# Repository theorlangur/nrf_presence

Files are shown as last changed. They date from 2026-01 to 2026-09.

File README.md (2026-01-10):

MCUBoot serial recovery:

speed issue:
changed ~/myapps/go/mynewt-mcumgr-cli/modified_mods/newtmgr@v0.0.0-20201028150837-60b2da78788c/nmxact/nmserial/serial_xport.go
specifically changed Sleep from 20ms to 1ms (there's one such sleep)
this upped transfer rate from ~ 830 bytes/s to ~ 4.5kb/s

speed issue update:
using mcumgr-client (rust-based tool), changed mtu to 4k and line input size to 8k
tweaked amount of retries + subsequent timeout duration (16 retries, 1000ms timeout)
and I'm getting an ok speed of ~ 6kb/s

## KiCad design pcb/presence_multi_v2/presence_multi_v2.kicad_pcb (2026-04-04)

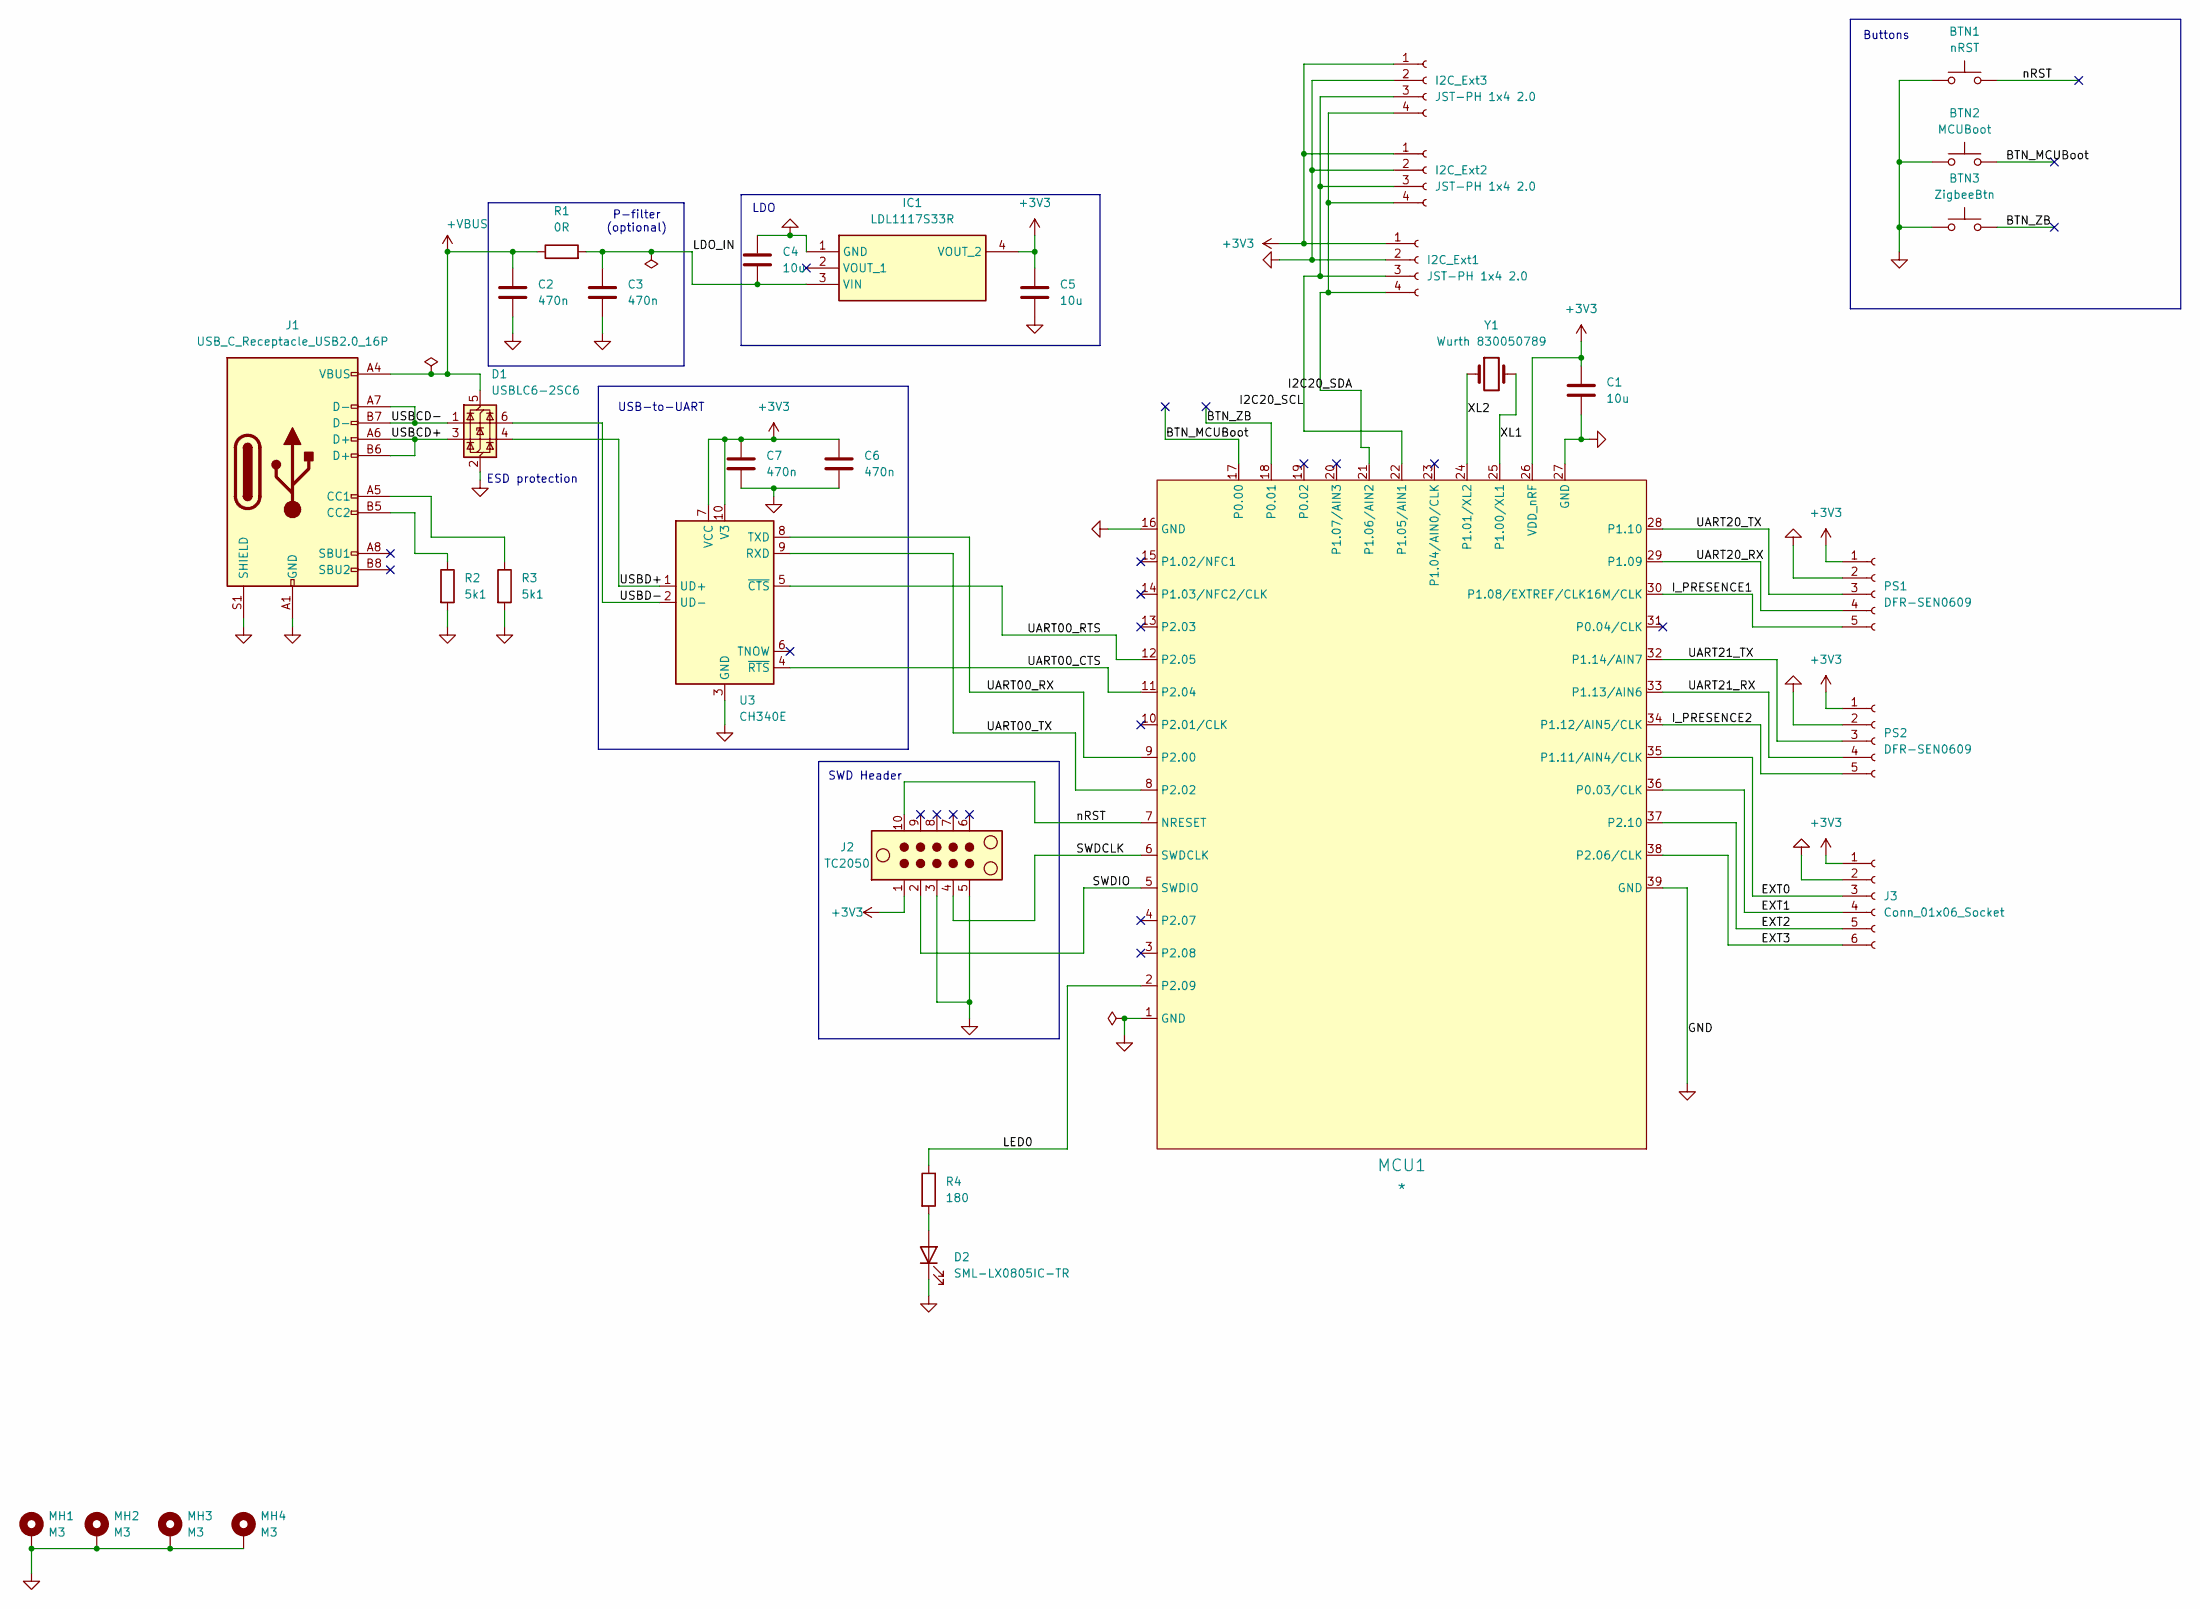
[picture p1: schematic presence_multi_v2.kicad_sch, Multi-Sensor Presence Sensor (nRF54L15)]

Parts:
BTN1: nRST; SW_SPST_TS-1088-xR020
BTN2: MCUBoot; SW_SPST_TS-1088-xR020
BTN3: ZigbeeBtn; SW_SPST_TS-1088-xR020
C1, C4, C5: 10u; C_0805_2012Metric
C2, C3, C6, C7: 470n; C_0805_2012Metric
D1: USBLC6-2SC6; SOT-23-6
D2: SML-LX0805IC-TR; LED_0805_2012Metric
I2C_Ext1, I2C_Ext2, I2C_Ext3: JST-PH 1x4 2.0; JST_PH_B4B-PH-K_1x04_P2.00mm_Vertical
IC1: LDL1117S33R; Mouser Part Number 511-LDL1117S33R
J1: USB_C_Receptacle_USB2.0_16P; USB_C_Receptacle_GCT_USB4105-xx-A_16P_TopMnt_Horizontal
J2: TC2050; Tag-Connect_TC2050-IDC-FP_2x05_P1.27mm_Vertical
J3: Conn_01x06_Socket; PinSocket_1x06_P2.54mm_Vertical
MCU1: *; Laird, BL54L15 Module, Platform Side
MH1, MH2, MH3, MH4: M3; MountingHole_3.5mm_Pad_Via
PS1, PS2: DFR-SEN0609; JST_PH_B5B-PH-K_1x05_P2.00mm_Vertical
R1: 0R; R_0805_2012Metric
R2, R3: 5k1; R_0805_2012Metric
R4: 180; R_0805_2012Metric
U3: CH340E; MSOP-10_3x3mm_P0.5mm
Y1: Wurth 830050789; Wurth-XTAL-830050789

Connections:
+3V3: C1.1, C5.1, C6.1, C7.1, I2C_Ext1.1, I2C_Ext2.1, I2C_Ext3.1, IC1.4 (VOUT_2), J2.1, J3.1, MCU1.26 (VDD_nRF), PS1.1, PS2.1, U3.7 (VCC), U3.10 (V3)
+VBUS: C2.1, D1.5 (VBUS), J1.A4 (VBUS), J1.A9 (VBUS), J1.B4 (VBUS), J1.B9 (VBUS), R1.1
/BTN_MCUBoot: BTN2.2, MCU1.17 (P0.00); also elsewhere on the board
/BTN_ZB: BTN3.2, MCU1.18 (P0.01); also elsewhere on the board
/EXT0: J3.3, MCU1.35 (P1.11/AIN4/CLK)
/EXT1: J3.4, MCU1.36 (P0.03/CLK)
/EXT2: J3.5, MCU1.37 (P2.10)
/EXT3: J3.6, MCU1.38 (P2.06/CLK)
/I2C20_SCL: I2C_Ext1.3, I2C_Ext2.3, I2C_Ext3.3, MCU1.22 (P1.05/AIN1)
/I2C20_SDA: I2C_Ext1.4, I2C_Ext2.4, I2C_Ext3.4, MCU1.21 (P1.06/AIN2)
/I_PRESENCE1: MCU1.30 (P1.08/EXTREF/CLK16M/CLK), PS1.5
/I_PRESENCE2: MCU1.34 (P1.12/AIN5/CLK), PS2.5
/LDO_IN: C3.1, C4.2, IC1.3 (VIN), R1.2
/LED0: MCU1.2 (P2.09), R4.1
/SWDCLK: J2.4, MCU1.6 (SWDCLK)
/SWDIO: J2.2, MCU1.5 (SWDIO)
/UART00_CTS: MCU1.11 (P2.04), U3.4 (~RTS)
/UART00_RTS: MCU1.12 (P2.05), U3.5 (~CTS)
/UART00_RX: MCU1.9 (P2.00), U3.8 (TXD)
/UART00_TX: MCU1.8 (P2.02), U3.9 (RXD)
/UART20_RX: MCU1.29 (P1.09), PS1.4
/UART20_TX: MCU1.28 (P1.10), PS1.3
/UART21_RX: MCU1.33 (P1.13/AIN6), PS2.4
/UART21_TX: MCU1.32 (P1.14/AIN7), PS2.3
/USBCD+: D1.3 (I/O2), J1.A6 (D+), J1.B6 (D+)
/USBCD-: D1.1 (I/O1), J1.A7 (D-), J1.B7 (D-)
/USBD+: D1.4 (I/O2), U3.1 (UD+)
/USBD-: D1.6 (I/O1), U3.2 (UD-)
/XL1: MCU1.25 (P1.00/XL1), Y1.2
/XL2: MCU1.24 (P1.01/XL2), Y1.1
/nRST: BTN1.2, J2.10, MCU1.7 (NRESET); also elsewhere on the board
GND: BTN1.1, BTN2.1, BTN3.1, C1.2, C2.2, C3.2, C4.1, C5.2, C6.2, C7.2, D1.2 (GND), D2.1 (K), I2C_Ext1.2, I2C_Ext2.2, I2C_Ext3.2, IC1.1 (GND), J1.A1 (GND), J1.A12 (GND), J1.B1 (GND), J1.B12 (GND), J1.S1 (SHIELD), J2.3, J2.5, J3.2, MCU1.1 (GND), MCU1.16 (GND), MCU1.27 (GND), MCU1.39 (GND), MH1.1, MH2.1, MH3.1, MH4.1, PS1.2, PS2.2, R2.2, R3.2, U3.3 (GND); also elsewhere on the board
unnamed: D2.2 (A), R4.2
unnamed: J1.A5 (CC1), R3.1
unnamed: J1.B5 (CC2), R2.1

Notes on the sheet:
SWD Header
ESD protection
P-filter (optional)
LDO
Buttons
USB-to-UART

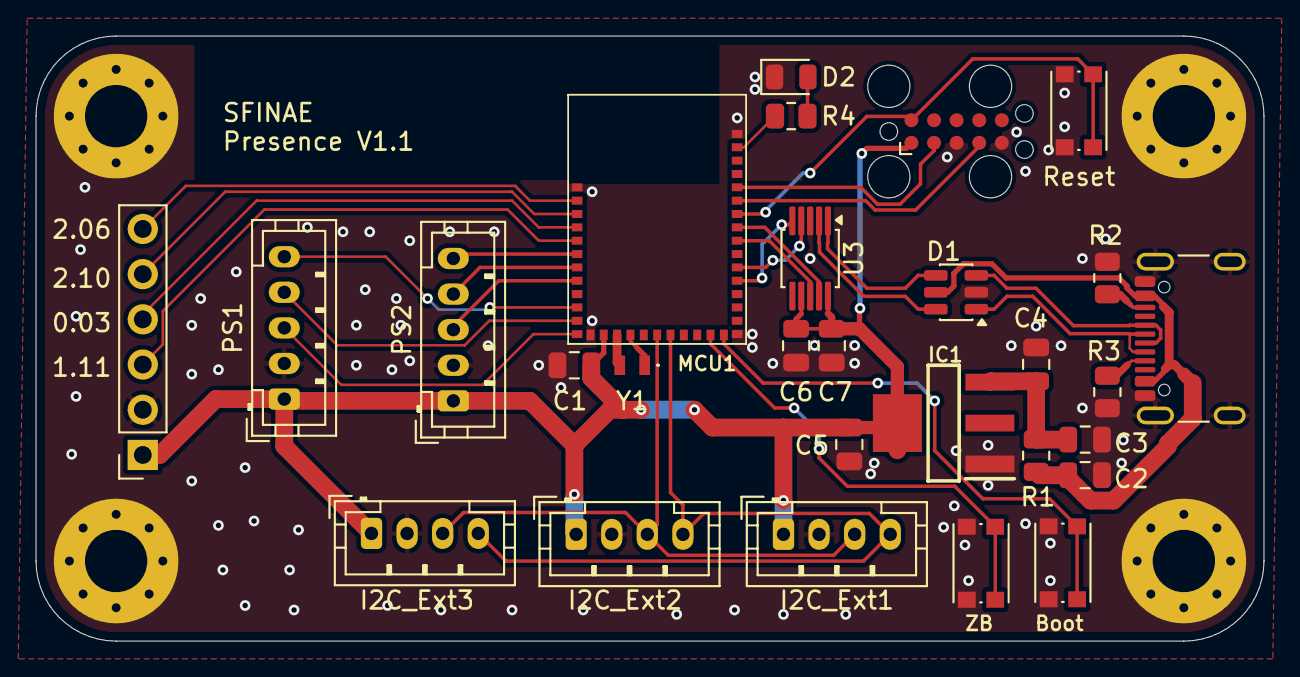
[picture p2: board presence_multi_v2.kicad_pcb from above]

Board: 2 copper layers, 69.0 x 34.0 mm, 32 parts (0 on the bottom side), 35 nets.

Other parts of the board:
Boot: MCUBoot; SW_Push_1P1T_NO_CK_KMR2
Reset: nRST; SW_Push_1P1T_NO_CK_KMR2
ZB: ZigbeeBtn; SW_Push_1P1T_NO_CK_KMR2

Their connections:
/BTN_MCUBoot: Boot.2; also elsewhere on the board
/BTN_ZB: ZB.2; also elsewhere on the board
/nRST: Reset.2; also elsewhere on the board
GND: Boot.1, Reset.1, ZB.1; also elsewhere on the board

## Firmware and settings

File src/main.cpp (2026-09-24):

/*
 * Copyright (c) 2023, Meta
 *
 * SPDX-License-Identifier: Apache-2.0
 */

#define FORCE_FMT
#define PRINTF_FUNC(...) printk(__VA_ARGS__)

#include <zephyr/kernel.h>
#include <zephyr/drivers/gpio.h>
#include <zephyr/settings/settings.h>
#include "ld2412_task.hpp"
#include <nrf_uart/periphery/lib_ld2412_formatters.hpp>
#include <dk_buttons_and_leds.h>
#include <nrf_general/led.h>

#include <zephyr/drivers/sensor.h>
#include <zephyr/drivers/sensor/ens160.h>

extern "C"{
#include <nrf_802154.h>
}

#include <zephyr/drivers/hwinfo.h>
#include <zephyr/drivers/watchdog.h>
#include <zephyr/storage/flash_map.h>
#include "threads_snapshot.hpp"
#include "partition_basic.hpp"
#include "activity_tracker.hpp"
/**********************************************************************/
/* Zigbee                                                             */
/**********************************************************************/
#include <nrfzbcpp/zb_main.hpp>
#include "zb/zb_mem_cfg.hpp"
#include <nrfzbcpp/zb_std_cluster_desc.hpp>
#include <nrfzbcpp/zb_status_cluster_desc.hpp>
#include <nrfzbcpp/zb_occupancy_sensing_cluster_desc.hpp>
#include <nrfzbcpp/zb_humid_cluster_desc.hpp>
#include <nrfzbcpp/zb_temp_cluster_desc.hpp>
#include <nrfzbcpp/zb_co2_cluster_desc.hpp>
#include <nrfzbcpp/zb_nstd_air_q_cluster_desc.hpp>
#include <nrfzbcpp/zb_tools.hpp>
#include "zb/zb_ld2412_cluster_desc.hpp"
#include "zb/zb_dev_ctrl_cluster_desc.hpp"

#include <atomic>

extern "C"{
#include <zephyr/debug/coredump.h>

void nrf_flash_skip_sync(bool skip);
}

constexpr bool kDebug = false;

#define BREADCRUMBS_PARTITION		breadcrumbs_partition
#define BREADCRUMBS_PARTITION_ID	FIXED_PARTITION_ID(BREADCRUMBS_PARTITION)

#if !FIXED_PARTITION_EXISTS(BREADCRUMBS_PARTITION)
#error "Need a fixed partition named 'breadcrumbs-partition'!"
#endif

/* Note that currently external memories are not supported */
#define FLASH_CONTROLLER	\
	DT_PARENT(DT_PARENT(DT_NODELABEL(BREADCRUMBS_PARTITION)))

#define FLASH_WRITE_SIZE	DT_PROP(FLASH_CONTROLLER, write_block_size)
#define FLASH_BUF_SIZE \
	MAX(FLASH_WRITE_SIZE, ROUND_UP(CONFIG_DEBUG_COREDUMP_FLASH_CHUNK_SIZE, FLASH_WRITE_SIZE))
#if DT_NODE_HAS_PROP(FLASH_CONTROLLER, erase_block_size)
#define DEVICE_ERASE_BLOCK_SIZE DT_PROP(FLASH_CONTROLLER, erase_block_size)
#else
/* Device has no erase block size */
#define DEVICE_ERASE_BLOCK_SIZE 1
#endif

#define MMWAVE_UART_NODE DT_ALIAS(mmwave_uart)
#define MMWAVE_UART_NODE2 DT_ALIAS(mmwave_uart2)
constinit const struct device *mmwave_uart1 = DEVICE_DT_GET(MMWAVE_UART_NODE);
constinit const struct device *mmwave_uart2 = DEVICE_DT_GET(MMWAVE_UART_NODE2);

/**********************************************************************/
/* LD2412 presence sensor configurations/data                         */
/**********************************************************************/
K_MSGQ_DEFINE_TYPED(ld2412::Queue, ld2412q_1);
K_MSGQ_DEFINE_TYPED(ld2412::Queue, ld2412q_2);

ld2412::Instance ld2412_1(ld2412q_1, mmwave_uart1, "ld2412_1");
ld2412::Instance ld2412_2(ld2412q_2, mmwave_uart2, "ld2412_2");

constinit static hlk::LD2412 *pLD2412_1 = nullptr;
constinit static hlk::LD2412 *pLD2412_2 = nullptr;

/**********************************************************************/
/* Zigbee Declarations and Definitions                                */
/**********************************************************************/
static bool g_ZigbeeReady = false;

/* Manufacturer name (32 bytes). */
#define INIT_BASIC_MANUF_NAME      "SFINAE"

/* Model number assigned by manufacturer (32-bytes long string). */
#define INIT_BASIC_MODEL_ID        "LD2412-NG"


/* Button used to enter the Bulb into the Identify mode. */
#define IDENTIFY_MODE_BUTTON            DK_BTN2_MSK

/* Button to start Factory Reset */
#define FACTORY_RESET_BUTTON IDENTIFY_MODE_BUTTON

/* Device endpoint, used to receive light controlling commands. */
constexpr int8_t kTX_POWER = 8;
constexpr uint8_t kMMW_EP = 1;
constexpr uint8_t kMMW_AUX_EP = 2;
constexpr uint16_t kDEV_ID = 0xBAAD;

constexpr uint16_t kInitialMinClearTimeout = 3;//seconds
constexpr uint32_t kZigbeeFloodProtectionTimeout = 1000;//ms
constexpr uint32_t kEnvSensorUpdateInterval = 15000;//ms
						    //
constexpr uint8_t kPersistentConfigVersion = 1;

struct device_ctx_t{
    zb::zb_zcl_basic_names_t basic_attr;
    zb::zb_zcl_status_t status_attr;
    zb::zb_zcl_status2_t status2_attr;
    zb::zb_zcl_dev_ctrl_t dev_attr;
    zb::zb_zcl_occupancy_pir_and_ultrasonic_t occupancy;
    zb::zb_zcl_on_off_attrs_client_t on_off_client;
    zb::zb_zcl_ld2412_t ld2412_main;
    zb::zb_zcl_ld2412_t ld2412_aux;
    zb::zb_zcl_rel_humid_basic_t humidity;
    zb::zb_zcl_temp_basic_t temperature;
    zb::zb_zcl_co2_basic_t co2;
    zb::zb_zcl_air_q_t airq;
};

//attribute shortcuts for template arguments

/**********************************************************************/
/* Status attribute shortcuts                                         */
/**********************************************************************/
constexpr auto kAttrStatus1 = &zb::zb_zcl_status_t::status1;
constexpr auto kAttrStatus2 = &zb::zb_zcl_status_t::status2;
constexpr auto kAttrStatus3 = &zb::zb_zcl_status_t::status3;

constexpr auto kA2Status1 = &zb::zb_zcl_status2_t::status1;
constexpr auto kA2Status2 = &zb::zb_zcl_status2_t::status2;
constexpr auto kA2Status3 = &zb::zb_zcl_status2_t::status3;
constexpr auto kA2Status4 = &zb::zb_zcl_status2_t::status4;

/**********************************************************************/
/* LD2412 attributes                                                  */
/**********************************************************************/
constexpr auto kAttrBaseCfg     = &zb::zb_zcl_ld2412_t::base_config;
constexpr auto kAttrStillThr    = &zb::zb_zcl_ld2412_t::still_energy_thresholds;
constexpr auto kAttrMoveThr     = &zb::zb_zcl_ld2412_t::move_energy_thresholds;
constexpr auto kAttrLightLevel  = &zb::zb_zcl_ld2412_t::light_level;
constexpr auto kAttrFlags       = &zb::zb_zcl_ld2412_t::flags;
constexpr auto kAttrBT          = &zb::zb_zcl_ld2412_t::bluetooth_state;
constexpr auto kAttrStatStill   = &zb::zb_zcl_ld2412_t::energy_stat_still;
constexpr auto kAttrStatMove    = &zb::zb_zcl_ld2412_t::energy_stat_move;
constexpr auto kAttrLightSense  = &zb::zb_zcl_ld2412_t::light_sense;
constexpr auto kAttrStatWinSize = &zb::zb_zcl_ld2412_t::statistics_sample_count_window;

/**********************************************************************/
/* Device control attributes                                          */
/**********************************************************************/
constexpr auto kAttrStillEnergyMain = &zb::zb_zcl_dev_ctrl_t::main_still_energy_analysis;
constexpr auto kAttrStillEnergyAux = &zb::zb_zcl_dev_ctrl_t::aux_still_energy_analysis;

/**********************************************************************/
/* Humidity                                                           */
/**********************************************************************/
constexpr auto kAttrHumid = &zb::zb_zcl_rel_humid_basic_t::measured_value;


/**********************************************************************/
/* Temperature                                                        */
/**********************************************************************/
constexpr auto kAttrTemp = &zb::zb_zcl_temp_basic_t::measured_value;

/**********************************************************************/
/* CO2                                                                */
/**********************************************************************/
constexpr auto kAttrCO2 = &zb::zb_zcl_co2_basic_t::measured_value;

/**********************************************************************/
/* Air quality                                                        */
/**********************************************************************/
constexpr auto kAttrTVOC = &zb::zb_zcl_air_q_t::tvoc;
constexpr auto kAttrAQI = &zb::zb_zcl_air_q_t::aqi;

/**********************************************************************/
/* Occupancy attribute shortcuts                                      */
/**********************************************************************/
constexpr auto kAttrOccupancy = &zb::zb_zcl_occupancy_ultrasonic_t::occupancy;
constexpr auto kAttrOccupancyToUnoccupancyDelay = &zb::zb_zcl_occupancy_ultrasonic_t::UltrasonicOccupiedToUnoccupiedDelay;

constexpr auto kCmdOn = &zb::zb_zcl_on_off_attrs_client_t::on;
constexpr auto kCmdOff = &zb::zb_zcl_on_off_attrs_client_t::off;

template<ld2412::Instance &i>
zb::cmd_handling_result_t on_cmd_restart();
template<ld2412::Instance &i>
zb::cmd_handling_result_t on_cmd_factory_reset();
template<ld2412::Instance &i>
zb::cmd_handling_result_t on_cmd_run_back_analysis();
template<ld2412::Instance &i>
zb::cmd_handling_result_t on_cmd_do_stat_snapshot();

zb::cmd_handling_result_t on_cmd_stop_wd_feeding();
zb::cmd_handling_result_t on_cmd_clear_coredump();

zb::cmd_handling_result_t on_cmd_start_analysis_for_presence();
zb::cmd_handling_result_t on_cmd_start_analysis_for_absence();
zb::cmd_handling_result_t on_cmd_stop_analysis();

/* Zigbee device application context storage. */
static constinit device_ctx_t dev_ctx{
    .basic_attr = {
	{
	    .zcl_version = ZB_ZCL_VERSION,
	    .power_source = zb::zb_zcl_basic_min_t::PowerSource::DC,
	},
	/*.manufacturer =*/ INIT_BASIC_MANUF_NAME,
	/*.model =*/ INIT_BASIC_MODEL_ID,
    },
    .status_attr{
	.cmd1 = {.cb = on_cmd_stop_wd_feeding}
	,.cmd2 = {.cb = on_cmd_clear_coredump}
    },
    .dev_attr{
	.cmd_start_analysis_for_presence = { .cb = on_cmd_start_analysis_for_presence }
	,.cmd_start_analysis_for_absense = { .cb = on_cmd_start_analysis_for_absence }
	,.cmd_stop_analysis              = { .cb = on_cmd_stop_analysis }
    },
    .ld2412_main{
	.still_energy_thresholds = zb::zb_zcl_ld2412_t::gate_array_t{100, 15, 15, 15, 15, 15, 15, 15, 15, 15, 15, 15, 15, 15}
	,.move_energy_thresholds = zb::zb_zcl_ld2412_t::gate_array_t{100, 15, 15, 15, 15, 15, 15, 15, 15, 15, 15, 15, 15, 15}
	,.cmd_restart = {.cb = on_cmd_restart<ld2412_1>}
	,.cmd_factory_reset = {.cb = on_cmd_factory_reset<ld2412_1>}
	,.cmd_run_background_analysis = {.cb = on_cmd_run_back_analysis<ld2412_1>}
	,.cmd_take_statistic_snapshot = {.cb = on_cmd_do_stat_snapshot<ld2412_1>}
    },
    .ld2412_aux{
	.still_energy_thresholds = zb::zb_zcl_ld2412_t::gate_array_t{100, 15, 15, 15, 15, 15, 15, 15, 15, 15, 15, 15, 15, 15}
	,.move_energy_thresholds = zb::zb_zcl_ld2412_t::gate_array_t{100, 15, 15, 15, 15, 15, 15, 15, 15, 15, 15, 15, 15, 15}
	,.cmd_restart = {.cb = on_cmd_restart<ld2412_2>}
	,.cmd_factory_reset = {.cb = on_cmd_factory_reset<ld2412_2>}
	,.cmd_run_background_analysis = {.cb = on_cmd_run_back_analysis<ld2412_2>}
	,.cmd_take_statistic_snapshot = {.cb = on_cmd_do_stat_snapshot<ld2412_2>}
    },
};

constinit static zb::device_full_t zb_ctx{
	zb::make_ep_args<{.ep=kMMW_EP, .dev_id=kDEV_ID, .dev_ver=1}>(
	    dev_ctx.basic_attr
	    , dev_ctx.status_attr
	    , dev_ctx.status2_attr
	    , dev_ctx.dev_attr
	    , dev_ctx.occupancy
	    , dev_ctx.ld2412_main
	    , dev_ctx.humidity
	    , dev_ctx.temperature
	    , dev_ctx.co2
	    , dev_ctx.airq
	    , dev_ctx.on_off_client
	),
	zb::make_ep_args<{.ep=kMMW_AUX_EP, .dev_id=kDEV_ID, .dev_ver=1}>(
	    dev_ctx.ld2412_aux
	)
};

/**********************************************************************/
/* Defining access to the global zigbee device context                */
/**********************************************************************/
//needed for proper command handling
struct zb::global_device
{
    static auto& get() { return zb_ctx; }
};

union status3_t
{
    uint16_t s;
    struct{
	uint16_t has_coredump: 1;
	uint16_t wdt_error: 1;
	uint16_t analysis_for_presence: 1;
	uint16_t analysis_for_absence: 1;
	uint16_t reset_reason_pin: 1;
	uint16_t reset_reason_wdt: 1;
	uint16_t reset_reason_sw: 1;
	uint16_t state_ld2412_back_main: 1;
	uint16_t state_ld2412_back_aux: 1;
	uint16_t state_ld2412_front_main: 1;
	uint16_t state_ld2412_front_aux: 1;
	uint16_t state_env: 1;
	uint16_t has_breadcrumbs: 1;
	uint16_t set_tx_error: 1;
	uint16_t incomplete_bread: 1;
	uint16_t osif_abort: 1;
    }bits;
};

//a shortcut for a convenient access
constinit static auto &zb_ep = zb_ctx.ep<kMMW_EP>();
constinit static auto &zb_ep_aux = zb_ctx.ep<kMMW_AUX_EP>();

template<ld2412::Instance &i>
auto& get_zb_ep_for_ld2412()
{
    if constexpr (&i == &ld2412_1)
	return zb_ep;
    else if constexpr (&i == &ld2412_2)
	return zb_ep_aux;
}

template<ld2412::Instance &i>
zb::zb_zcl_ld2412_t& get_data_for_ld2412()
{
    if constexpr (&i == &ld2412_1)
	return dev_ctx.ld2412_main;
    else if constexpr (&i == &ld2412_2)
	return dev_ctx.ld2412_aux;
}

template<ld2412::Instance &i>
const char* get_name_for_ld2412()
{
    if constexpr (&i == &ld2412_1)
	return "main";
    else if constexpr (&i == &ld2412_2)
	return "aux";
}

template<ld2412::Instance &i>
constexpr uint8_t get_ld2412_idx()
{
    if constexpr (&i == &ld2412_1)
	return 0;
    else if constexpr (&i == &ld2412_2)
	return 1;
}

/**********************************************************************/
/* Device defines                                                     */
/**********************************************************************/
/* The devicetree node identifier for the "led0" alias. */
#define LED0_NODE DT_ALIAS(userled0)

/*
 * A build error on this line means your board is unsupported.
 * See the sample documentation for information on how to fix this.
 */
static const struct gpio_dt_spec led0 = GPIO_DT_SPEC_GET(LED0_NODE, gpios);

///* Get the node from the alias */
#define SENSOR_NODE DT_ALIAS(presence)
#define SENSOR_NODE2 DT_ALIAS(presence2)
#define PIR_NODE2 DT_ALIAS(pir)

/* Get the GPIO spec directly from the node */
/* Note: We look for the property "gpios" inside the node */
static const struct gpio_dt_spec presence = GPIO_DT_SPEC_GET(SENSOR_NODE, gpios);
static const struct gpio_dt_spec presence2 = GPIO_DT_SPEC_GET(SENSOR_NODE2, gpios);
static const struct gpio_dt_spec pir = GPIO_DT_SPEC_GET(PIR_NODE2, gpios);

static const struct device *const eco2sensor = DEVICE_DT_GET(DT_NODELABEL(eco2sensor));
static const struct device *const rht2sensor = DEVICE_DT_GET(DT_NODELABEL(rht2sensor));

/**********************************************************************/
/* Template helper. TODO: move to some generic lib                    */
/**********************************************************************/
template<class T>
struct method_1st_arg_t;

template<class T, class Arg>
struct method_1st_arg_t<void(T::*)(Arg)>
{
    using type = Arg;
};

template<auto pM>
using arg1_type_t = method_1st_arg_t<decltype(pM)>::type;

template<auto &inst, auto M>
void method_fwd(arg1_type_t<M> a)
{
    (inst.*M)(a);
}

template<size_t N>
auto as_print_dest(zb::zigbee_str_t<N> &str)
{
    return tools::BufferFormatter(str.name + 1, str.capacity());
}

template<uint8_t kFlag>
using activity_t = zephyr::activity_t<kFlag>;
using zephyr::kLD2412_Front_Main;
using zephyr::kEnv;
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
int main(void)
{
    static_assert(atomic_state_t::is_always_lock_free);
    disable_hw_wdt();

    if (wdt_snapshot.is_valid())
    {
	//write into coredump section
	dump_wdt_snapshot_to_flash();
	wdt_snapshot.clear();
    }else if (wdt_snapshot.magic == zephyr::kSnapshotMagicNotReady)
    {
	printk("unfinished WDT snapshot detected\r\n");
	wdt_snapshot.clear();
    }

    int err = settings_subsys_init();
    hwinfo_get_reset_cause(&reset_reasons);
    hwinfo_clear_reset_cause();

    led::setup();
    led::start();

    zb::g_GlobalErrorHandler = ultimate_zb_fail;

    //configure button handler
    err = dk_buttons_init(button_changed);
    if (dk_get_buttons() & FACTORY_RESET_BUTTON)
    {
	//zigbee button is pressed
	zigbee_erase_persistent_storage(true);
	led::show_pattern(led::kPATTERN_4_BLIPS_NORMED, 500);
    }
    //assign a button for a factory reset procedure
    register_factory_reset_button(FACTORY_RESET_BUTTON);

    printk("main\r\n");

    pLD2412_1 = ld2412_1.setup(&on_ld2412_error<ld2412_1>, &on_ld2412_notify<ld2412_1>, 0, wdt_snapshot.flags);
    if(!pLD2412_1)
    {
	printk("LD2412 not found\r\n");
	int val = 1;
	while(true)
	{
	    gpio_pin_set_dt(&led0, val);
	    k_msleep(1000);
	    val ^= 1;
	    printk("LD2412 not found; led: %d\r\n", val);
	}
	return 0;
    }

    pLD2412_2 = ld2412_2.setup(&on_ld2412_error<ld2412_2>, &on_ld2412_notify<ld2412_2>, 1, wdt_snapshot.flags);
    if (!pLD2412_2)
    {
	printk("LD2412(aux) not found\r\n");
	int val = 1;
	while(true)
	{
	    gpio_pin_set_dt(&led0, val);
	    k_msleep(500);
	    val ^= 1;
	    printk("LD2412(aux) not found; led: %d\r\n", val);
	}
	return 0;
    }

    dev_ctx.occupancy.occupancy = false;

    /* Register callback for handling ZCL commands. */
    auto dev_cb = zb::tpl_device_cb<
	zb::dev_cb_handlers_desc_t{ .error_handler = on_dev_cb_error }
	//main instance
	, zb::handle_set_for<kAttrBaseCfg,               &on_set_base_config<ld2412_1>>(zb_ep)
	, zb::handle_set_for<kAttrLightSense,            &on_set_light_sense<ld2412_1>>(zb_ep)
	, zb::handle_set_for<kAttrStillThr,              method_fwd<ld2412_1, &ld2412::Instance::set_still_thresholds_raw>>(zb_ep)
	, zb::handle_set_for<kAttrMoveThr,               method_fwd<ld2412_1, &ld2412::Instance::set_move_thresholds_raw>>(zb_ep)
	, zb::handle_set_for<kAttrStatWinSize,           on_stat_win_size<ld2412_1>>(zb_ep)
	, zb::handle_set_for<kAttrOccupancyToUnoccupancyDelay, &on_change_occ_to_unocc>(zb_ep)
	, zb::handle_set_for<kAttrBT,                    method_fwd<ld2412_1, &ld2412::Instance::switch_bluetooth>>(zb_ep)
	//aux instance
	, zb::handle_set_for<kAttrBaseCfg,               &on_set_base_config<ld2412_2>>(zb_ep_aux)
	, zb::handle_set_for<kAttrLightSense,            &on_set_light_sense<ld2412_2>>(zb_ep_aux)
	, zb::handle_set_for<kAttrStillThr,              method_fwd<ld2412_2, &ld2412::Instance::set_still_thresholds_raw>>(zb_ep_aux)
	, zb::handle_set_for<kAttrMoveThr,               method_fwd<ld2412_2, &ld2412::Instance::set_move_thresholds_raw>>(zb_ep_aux)
	, zb::handle_set_for<kAttrStatWinSize,           on_stat_win_size<ld2412_2>>(zb_ep_aux)
	, zb::handle_set_for<kAttrBT,                    method_fwd<ld2412_2, &ld2412::Instance::switch_bluetooth>>(zb_ep_aux)
    >;

    ZB_ZCL_REGISTER_DEVICE_CB(dev_cb);

    /* Register device context (endpoints). */
    ZB_AF_REGISTER_DEVICE_CTX(zb_ctx);

    err = settings_load();

    //real config from the device takes precedense
    update_dev_ctx_from_ld2412<ld2412_1>();
    update_dev_ctx_from_ld2412<ld2412_2>();

    app_cfg_nvram_register();

    if (int err = configure_presence_pins(); err != 0)
    {
	printk("Failed to configure c4001 out pin\r\n");
    }
    {
	int p1 = gpio_pin_get_dt(&presence);
	int p2 = gpio_pin_get_dt(&presence2);
	int pirVal = gpio_pin_get_dt(&pir);
	g_presence_state = p1 | p2 | pirVal;
	printk("Presence pin state: %d\r\n", g_presence_state);
	dev_ctx.occupancy.occupancy = g_presence_state;
    }
    zigbee_enable();
    g_zboss_thread_id = zigbee_thread_id();

    printk("Main: sleep forever\r\n");
    FMT_PRINTLN("-----LD2412 main-----");
    print_ld2412_config(*pLD2412_1);
    FMT_PRINTLN("-----LD2412 aux-----");
    print_ld2412_config(*pLD2412_2);

    k_thread_start(env_sense_thread);
    while (1) {
	k_sleep(K_FOREVER);
    }

    return 0;
}

int configure_presence_pins()
{
    PresenceChange state;
    gpio_pin_configure_dt(&led0, GPIO_OUTPUT_ACTIVE);
    int err = gpio_pin_configure_dt(&presence, GPIO_INPUT);
    if (err != 0)
    {
	printk("(main)gpio_pin_configure_dt: %d\r\n", err);
	return err;
    }
    gpio_pin_set_dt(&led0, 0);

    err = gpio_pin_interrupt_configure_dt(&presence, GPIO_INT_EDGE_BOTH);
    if (err != 0)
    {
	printk("(main)gpio_pin_interrupt_configure_dt: %d\r\n", err);
	return err;
    }
    g_ld2412_main_presence_out = gpio_pin_get_dt(&presence);
    state.bits.main = g_ld2412_main_presence_out;
    printk("(main)initial: %d\r\n", g_ld2412_main_presence_out);

    err = gpio_pin_interrupt_configure_dt(&presence2, GPIO_INT_EDGE_BOTH);
    if (err != 0)
    {
	printk("(aux)gpio_pin_interrupt_configure_dt: %d\r\n", err);
	return err;
    }
    g_ld2412_aux_presence_out = gpio_pin_get_dt(&presence2);
    state.bits.aux = g_ld2412_aux_presence_out;
    printk("(aux)initial: %d\r\n", g_ld2412_aux_presence_out);

    err = gpio_pin_configure_dt(&pir, GPIO_INPUT);
    if (err != 0)
    {
	printk("(pir)gpio_pin_configure_dt: %d\r\n", err);
	return err;
    }
    err = gpio_pin_interrupt_configure_dt(&pir, GPIO_INT_EDGE_BOTH);
    if (err != 0)
    {
	printk("(pir)gpio_pin_interrupt_configure_dt: %d\r\n", err);
	return err;
    }
    g_pir_presence = gpio_pin_get_dt(&pir);
    state.bits.pir = g_pir_presence;

    dev_ctx.occupancy.occupancy = g_pir_presence;//initially only conservatively by PIR
    dev_ctx.status_attr.status2 = get_presence_as_status(state.val);

    g_ld2412_main_presence_out = gpio_pin_get_dt(&presence);
    g_ld2412_aux_presence_out = gpio_pin_get_dt(&presence2);

    gpio_init_callback(&g_on_ld2412_triggered_main, presence_triggered, BIT(presence.pin));
    err = gpio_add_callback_dt(&presence, &g_on_ld2412_triggered_main);
    if (!err)
    {
	gpio_init_callback(&g_on_ld2412_triggered_aux, presence_triggered, BIT(presence2.pin));
	err = gpio_add_callback_dt(&presence2, &g_on_ld2412_triggered_aux);
	if (!err)
	{
	    gpio_init_callback(&g_on_pir_triggered, presence_triggered, BIT(pir.pin));
	    err = gpio_add_callback_dt(&pir, &g_on_pir_triggered);
	    if (err != 0)
		printk("(pir)gpio_add_callback_dt: %d\r\n", err);
	}else
	    printk("(aux)gpio_add_callback_dt: %d\r\n", err);
    }else
	printk("(main)gpio_add_callback_dt: %d\r\n", err);
    return err;
}

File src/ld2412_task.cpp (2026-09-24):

#include "ld2412_task.hpp"
#include "activity_tracker.hpp"
#include <lib_misc_helpers.hpp>
#include <nrf_uart/periphery/lib_ld2412_formatters.hpp>

namespace ld2412
{
    Instance::Instance(Queue &q, const struct device *uart, const char* thread_name):
	m_ThreadName(thread_name)
	, m_Q(q)
	, m_pUART(uart)
	, m_Sensor(uart)
    {
    }

    hlk::LD2412* Instance::setup(err_callback_t err, notify_callback_t notification, uint8_t idx, volatile uint8_t &flags)
    {
	m_Idx = idx;
	m_pFlags = &flags;
	m_ThreadID = {};
	if (!device_is_ready(m_pUART))
	{
	    printk("uart for ld2412 is not ready\r\n");
	    return {};
	}

	zephyr::activity_rt_t track(*m_pFlags, zephyr::kLD2412_Back_Main << m_Idx);
	auto r = m_Sensor.Init();
	if (!r)
	    return {};

	r = m_Sensor.ChangeConfiguration()
	    .SetSystemMode(hlk::LD2412::SystemMode::Energy)
	.EndChange();
	if (!r)
	    return {};

	m_ErrCB = err;
	m_NotifyCB = notification;

	m_ThreadID = k_thread_create(&m_Thread 
	    ,m_ThreadStack
	    ,sizeof(m_ThreadStack)
	    ,thread_func
	    ,this, nullptr, nullptr
	    ,THREAD_PRIORITY
	    , 0
	    , {0});
	if (!m_ThreadID)
	    return {};
	k_thread_name_set(m_ThreadID, m_ThreadName);
	return &m_Sensor;
    }

    hlk::LD2412* Instance::sensor()
    {
	if (m_ThreadID)
	    return &m_Sensor;
	else
	    return {};
    }

    void Instance::restart()
    {
	m_Q << restart_cfg_t{};
    }
    void Instance::reload_config()
    {
	m_Q << reload_cfg_t{};
    }
    void Instance::factory_reset()
    {
	m_Q << factory_reset_cfg_t{};
    }
    void Instance::switch_bluetooth(bool on)
    {
	m_Q << bt_cfg_t{.on = on};
    }
    void Instance::set_basic_config(basic_cfg_t const& cfg)
    {
	m_Q << cfg;
    }
    void Instance::set_light_sense(light_sense_cfg_t const& cfg)
    {
	m_Q << cfg;
    }
    void Instance::set_still_thresholds(still_thresholds_cfg_t const& cfg)
    {
	FMT_PRINTLN("{} still thresholds: {}", m_ThreadName, cfg.still_thresholds);
	m_Q << cfg;
    }
    void Instance::set_move_thresholds(move_thresholds_cfg_t const& cfg)
    {
	FMT_PRINTLN("{} move thresholds: {}", m_ThreadName, cfg.move_thresholds);
	m_Q << cfg;
    }
    void Instance::run_back_analysis(run_background_analysis_t const& cfg)
    {
	m_Q << cfg;
    }
    void Instance::collect_statistics(uint8_t win_size)
    {
	m_Q << collect_statistics_cfg_t{win_size};
    }
    void Instance::take_statistic_snapshot(snapshot_statistics_cfg_t const& cfg)
    {
	m_Q << cfg;
    }

    void Instance::start_analysis_for_presence(start_analysis_for_presence_t const& cfg)
    {
	m_Q << cfg;
    }

    void Instance::start_analysis_for_absence(start_analysis_for_absence_t const& cfg)
    {
	m_Q << cfg;
    }

    void Instance::stop_analysis(stop_analysis_t const& cfg)
    {
	m_Q << cfg;
    }

    void Instance::get_analysis_results(hlk::LD2412::gate_array_t &results)
    {
	results = m_AnalysisStillEnergies;
    }

    void Instance::thread_func(void *_pThis, void *, void *)
    {
	Instance *pThis = (Instance*)(_pThis);
	return pThis->mainloop();
    }

    void Instance::collect_sample()
    {
	if (m_StatSampleCount)//we're collecting statistics
	{
	    auto &sample = m_StatSampleBuffer[m_StatSampleIndex];
	    sample.still_energies = m_Sensor.GetAllMeasuredStillEnergies();
	    sample.move_energies = m_Sensor.GetAllMeasuredMoveEnergies();
	    m_StatSampleIndex = (m_StatSampleIndex + 1) % m_StatSampleCount;
	    ++m_TotalSamplesWritten;
	}

	if (m_Analysis != AnalysisState::Stopped)
	{
	    auto const &measured = m_Sensor.GetAllMeasuredStillEnergies();
	    for(size_t i = 0; i < measured.size(); ++i)
	    {
		if (m_Analysis == AnalysisState::RunningForPresence)
		{
		    if (m_AnalysisStillEnergies[i] > measured[i])
			m_AnalysisStillEnergies[i] = measured[i];
		}
		if (m_Analysis == AnalysisState::RunningForAbsence)
		{
		    if (m_AnalysisStillEnergies[i] < measured[i])
			m_AnalysisStillEnergies[i] = measured[i];
		}
	    }
	}
    }

    void Instance::check_back_analysis()
    {
	if (m_BackgroundAnalysisDoneCB)
	{
	    run_background_analysis_t::Result r;
	    switch(m_Sensor.GetPresence().m_State)
	    {
		case hlk::LD2412::TargetState::BackgroundAnalysisOk:
		    r = run_background_analysis_t::Result::Ok;
		    break;
		case hlk::LD2412::TargetState::BackgroundAnalysisFailed:
		    r = run_background_analysis_t::Result::Failed;
		    break;
		case hlk::LD2412::TargetState::BackgroundAnalysisRunning:
		    return;
		default:
		    if (m_Sensor.IsDynamicBackgroundAnalysisRunning())
			return;
		    //assuming done
		    r = run_background_analysis_t::Result::Ok;
		    break;
	    }

	    m_BackgroundAnalysisDoneCB(r);
	    m_BackgroundAnalysisDoneCB = nullptr;

	    auto res = m_Sensor.ChangeConfiguration()
		.SetSystemMode(hlk::LD2412::SystemMode::Energy)
	    .EndChange();
	    if (!res)
	    {
		FMT_PRINTLN("{} Switching to Energy mode failed with: {}", m_ThreadName, res.error());
		if (m_ErrCB)
		    m_ErrCB(err_t::EnergyModeAfterBackAnalysis);
	    }
	}
    }

    void Instance::mainloop()
    {
	QueueItem q;
	bool processMessage = true;
	bool readFrameNow = false;

	auto last_frame_time = k_uptime_get();

	while(1)
	{
	    if (m_StatSampleCount || m_BackgroundAnalysisDoneCB || m_Analysis != AnalysisState::Stopped)
		readFrameNow = true;
	    else
	    {
		auto interval = m_LightSensorUpdateInterval;
		readFrameNow = (k_uptime_get() - last_frame_time) >= interval;
	    }

	    if (readFrameNow)
	    {
		zephyr::activity_rt_t track(*m_pFlags, zephyr::kLD2412_Back_Main << m_Idx);
		auto r = m_Sensor.TryReadSingleFrame(3, hlk::LD2412::Drain::Try);
		if (r)
		{
		    last_frame_time = k_uptime_get();
		    collect_sample();
		    check_back_analysis();
		}else
		    ++m_FrameReadErrorCount;
		processMessage = m_Q.Recv(q, K_NO_WAIT) == 0;
	    }
	    else
	    {
		m_Q >> q;
		processMessage = true;
	    }
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

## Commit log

2025-12-13 added kicad folder with schematics and other stuff
    [presence_multi_v2.kicad_pcb, presence_multi_v2.kicad_sch]
2025-12-13 started actual PCB design
    [presence_multi_v2.kicad_pcb, presence_multi_v2.kicad_sch]
2025-12-14 replaced ASM1117 with LDL1117, removed 8 pin socket, added 3 4-pin JST-PH connectors
    [presence_multi_v2.kicad_pcb, presence_multi_v2.kicad_sch]
2025-12-15 added buttons, configured PCB settings
    removed layers
    configured pre-defined ruls (constraints)
    added default sizes
    [presence_multi_v2.kicad_pcb, presence_multi_v2.kicad_sch]
2025-12-15 added GND net with color, updated PCB
    imported GND net, imported MCUBoot color
    [presence_multi_v2.kicad_sch]
2025-12-15 added a dedicated button for zigbee
    [presence_multi_v2.kicad_pcb, presence_multi_v2.kicad_sch]
2025-12-15 routing PCB
    [presence_multi_v2.kicad_pcb]
2025-12-16 ready version
    [presence_multi_v2.kicad_pcb, presence_multi_v2.kicad_sch]
2025-12-16 adjusted edge cuts (same radius used); adjusted some labels
    [presence_multi_v2.kicad_pcb]
2025-12-16 added info on components to a silkscreen
    [presence_multi_v2.kicad_pcb]
2026-01-09 refactored usb-to-uart into own dtsi
2026-01-09 added led blinking when dev not found
2026-01-09 MCUBoot: configured UART00 and using HW flow control
    important quirk: speed needs to be configured to 115200 so that the real
    speed 921600 can be used
2026-01-09 working version with MCUBoot
    had to adjust partition sizes
    MCUBoot partition is auto-calculated and the app offset is placed at a
    weird location
    adjusted atm the whole thing so that the slot0 is at 0xf800
    it works
    but 'list' command doesn't show any valid images
    [main.cpp]
2026-01-09 ok, the reason or baudrate mismatch is 128MHz clock frequence for uart00 instead of 16MHz
    so the requested 115200 are basically scaled up 8x to 921600
2026-01-09 added script to get uart output from usb-to-uart on board
2026-01-11 for whatever reason uart20 doesn't work well with pins 1.09 and 1.10 for rx/tx
    uart22 does
2026-01-11 circled back to uart20
    the reason was pinctrl misconfiguration
    original board pinctrl config provided pinconfig for uart20 in 2 groups
    with CTS pin and a different RX pin
    harmonized
2026-01-11 added 1 check for validity of uart
2026-01-12 added save/reset config to c4001 cluster description
    [main.cpp]
2026-01-12 added logic to reset zigbee when zigbee button is hold when reset
    [main.cpp]
2026-01-13 added configuration for i2c, added environment fetching
    using i2c21 instance since uart20 is already in use
    added clusters for temp/humidity/co2/tvoc/aqi
2026-01-13 forgot to start led thread
    also giving time for led to blink
2026-01-13 increased timeout, using udev rule to reference usb-to-uart ch340
2026-01-14 added 'Cortex-Debug' extension and enabled thread info
    finally I can see stack traces of all threads...
2026-01-18 enabled 2nd EP and added support for 2nd C4001 presence sensor
2026-01-18 2 c4001 sensors compile and run, as also 2 endpoints
2026-01-18 using dedicated symlink for running minicom for uart
2026-01-31 PCB: adjsuted DRU (were too strict)
2026-01-31 PCB: re-arranged the whole board
    made it significantly smaller
    used a slightly different footprint for buttons
    USB-C should be placed symmetrically now
    [presence_multi_v2.kicad_pcb]
2026-02-02 fixed bug with a presence logic
    pin 2 was ignored basically
    [main.cpp]
2026-02-02 added TX power support
2026-02-04 left one slot partition, increased the size of it
    was needed for dbg zigbee
2026-02-04 attempt to reboot like that causes a crash
    not rebooting...
    [main.cpp]
2026-02-04 increased resources for zigbee in attempt to fix stability of the device in router mode
    [main.cpp]
2026-02-06 this all probably doesn't play a role since the actual problem is in endless broadcasting and requesting for addresses
    [main.cpp]
2026-02-07 default end-device config doesn't work reliably. apparently the MCU suffocates
    brought back this config:
    End-Device
    and increased parameters like RX buffers, network size, what-not
    [main.cpp]
2026-02-08 switched to RTT loggin
2026-02-11 added PIR sensor logic
2026-02-14 implementing requests to LD2412 task
    implemented snapshotting the collected statistics
    also the sensor is put into engineering mode from the start
    (needed for light sensing, energy config)
2026-02-15 implementing missing parts...
    on_get_stat_snapshot, on_back_analysis_done
    added get_data_for_ld2412, get_zb_ep_for_ld2412 helpers to get
    zb_ep/data structs depending on actual instance
    [main.cpp]
2026-02-15 more work towards working ld2412 logic
    * added 'update_*' functions to update zigbee attributes from actual
    state of the device
    * implemented error handling for changing parameters
    * implemented initial configuration assignment on the start
    [main.cpp]
2026-02-15 removed tx power control
2026-02-15 re-worked interrupt processing
    all goes via 1 ISR
    PIR is dominant for detection
    but secondary for holding
2026-02-22 aux ld2412 had wrong uart speed
2026-02-22 fixing initial presence evaluation
    [main.cpp]
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2026-02-23 ld2412: config changes are accompanied by immediate reads from the sensor
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2026-02-28 increased allow sample count for statistic to 255, updated ld2412 submodule
2026-03-05 changing mode back to router
    hoping with libzboss fixed (sending to bound) it'll behave
    nicely
    [main.cpp]
2026-03-10 implemented logic for initial presence detection
    when we first encounter presence we start the reset protection timer
    and we don't change the occupancy state until the timer runs out
    important bit: the decisions are made in zb-thread, based on the state
    that is changed only in zb-thread. so no weird 'time-travel' with
    older zb callback seing newer states
    [main.cpp]
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2026-03-15 this seems to stabilize operating of the device as a router
    with defaults I was observing weird leave-rejoin behavior and delayed
    reactions
    [main.cpp]
2026-03-15 fixed min/max stat collection
    [ld2412_task.cpp]
2026-03-15 End-Device seems to be more stable than router unfortunately
2026-03-15 fixed a bug
    all but bit 0 should've been erased
    [main.cpp]
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2026-04-04 changed PCB thickness, changed origin (better integration with FreeCAD)
    [presence_multi_v2.kicad_pcb]
2026-05-17 added timer/cmd sending failure routines
    just to blink with a led for info
    [main.cpp]
2026-05-17 using zigbee string's 'capacity' + added ultimate zb failure handler
    [main.cpp]
2026-05-22 using atomics to reduce the amount of zb_schedule_app_callback calls
    g_PresenceChangeState: unset state is 0; it's or-ed in 'changed' flags
    and simply added last state. CAS-loop to set/add atomically latest
    change state before it was processed by zigbee thread
    g_PresenceHWState: last real presence registered state to be processed
    by send_on_off. 'val' passed to send_on_off says if the request is from
    a real presence or not (based on the OnOffVirtualMask)
2026-05-23 adding atomics to combine multiple frequent changes of presence state didn't help
    this commit attempts to flood-gate sending zigbee commands and changes
    basically I'm not allowing sending on/off commands and a presence attribute
    change more often than kZigbeeFloodProtectionTimeout milliseconds.
    g_DelayedVal is not atomic since reading/writing there happens only from
    zigbee thread
    [main.cpp]
2026-05-24 turning on coredumps to flash and switched to fully static partition management
    otherwise the system didn't want to add the coredump_partition although
    it was defined in partitions.dtsi
2026-05-26 added querying coredump and an artificial crash to store one
    [main.cpp]
2026-06-27 added configs for building with experimental gcc16.1 toolchain
    had to fix several compiler errors (casting from packed struct members)
    added also tasks to run VSCode with a proper environment
    [main.cpp]
2026-06-29 changed watchdog strategy
    nordic's hardware watchdog bites
    if it was fired I have mere tens of microseconds to do something
    it's not enough to write a coredump
    so 2-stage watchdog scheme is used: task watchdog from zephyr based on
    the timers + hw watchdog as a last-hope-fallback to reset
    also added '-fno-omit-frame-pointer' when coredumps are enabled
    I need reasonable stacks...
    [main.cpp]
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2026-06-30 actually working coredump via explicit skipping the sync before k_panic
    [main.cpp]
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2026-07-02 wrong comparison conditions + added code to verify the mode (must be energy)
    [ld2412_task.cpp]
2026-07-15 added support to stat3 to show last reset reason
    [main.cpp]
2026-07-16 resetting reset_reasons on 'clear coredump' cmd
    [main.cpp]
2026-07-16 moved settings load after zigbee ctx was configured
    trying to fix proper data restoration
    [main.cpp]
2026-07-18 multple fixes and changes to snapshot mechanism
    using k_thread_foreach_unlocked to iterate over all threads and capture
    their stacks
    writing the snapshot on next start to the dedicated breadcrumbs_partition
    [main.cpp]
2026-07-18 enabled thread monitor and -fno-omit-frame-pointer for the whole project (with ZephyrOS itself)
2026-07-18 improving reaction after watchdog reset
    sending on or off command based on current presence state
    [main.cpp]
2026-07-18 fixing py script printing symbolized addresses
2026-07-18 capturing breadcrumbs on fatal error
    [main.cpp]
2026-07-19 improving snapshot, improving snapshotting at fault handling
    in case of a fault: first 3 entries:
    reason, exc_return, cfsr
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2026-07-19 relocating sensor fetching to a separate task
    suspecting timings screw-up because of the sensor data fetcing in zigbee
    thread itself
2026-07-19 added a compile-time check for extra frames amount
2026-07-21 various changes
    * increased wdt timeout to 7s
    * moved zb_ctx init to signal handler on first signal (meaning zboss is
    definitely operational)
    * increased stack size for env sensor thread to 1K
2026-08-12 removed debug build, added latency tracking, added tx-power set
2026-08-12 wrapping at linking stage actually working
    had to add linking options as 'public'
2026-08-12 I think I found the reason for bad latencies when reacting to presence
    zb_schedule_app_callback -> doesn't wake up zigbee thread if it sleeps
    zigbee_schedule_callback -> does wake up thread, also correctly works in
    ISR
    [main.cpp]
2026-08-15 changed latency/error tracking to only rx/tx in total and latency overall
    no detailed
    [main.cpp]
2026-08-17 fixed receive error tracking
    [main.cpp]
